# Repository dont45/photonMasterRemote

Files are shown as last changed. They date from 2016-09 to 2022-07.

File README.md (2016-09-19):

# photonMasterRemote
A photon Master Alarm system with any number of optional photon Remote nodes

See Wiki for lots more detail

Common source generates a master alarm node or a remote node.  
The master node is created by the #define PHOTON_MASTER line in parms.h.
A remote node is created by commenting out the master node #define , i.e. 
//#define PHOTON_MASTER which will result in a #define PHOTON_REMOTE
In addition, you must inclue the line #define REMOTE_SYSTEM_ID 1
The id number must be 1 or greater.  The id of the master node must be 0.

The master my have any number of it's own sensors defined in writeTestConfiguration.
The master's representation of a remote sensor is defined with device.use set to
SUB_REMOTE_THERMOMETER or SUB_REMOTE_SENSOR.  
The actual sensor is defined in the remote with master_idx set to the index number 
in the master which represents the remote sensor.

Communication of the remote sensor status is done via a particle.publish string which represents
the state of all of the remote sensors, such as:
3@1@T@13:12:16@TEST DOOR:2:0.000000:3@OUTSIDE TEMP:3:89.937500:0$
The @ character separates the first four data fields (sequence,remote id, alert type, and time).
Data for each sensor follows, also separated by an @ character.
These fields are parsed by the class Parse.

Each sensor's data fields are separated by a : character.  They are Name,device index in master,
and sensor reading.  These data fields are also parsed by class Parse.

The remote node publishes 'remoteData' to the particle cloud, and the master node is subscribed
to this cloud data field.  The remote node performs a publish immediately upon any sensor being
tripped, and also periodically as an Information update on a specified schedule, set in
parms.h.  This allows for immediate response to an alarm condition and periodic read on the
master node of other less time-sensitive data such as a temperature probe.  Upon receipt of the
subscribed remoteData, the master device is update with the new sensor data, stored into the
device record as dev_reading, and the current time is stored into dev_last_read.

In my operational test system, the hardware for both master and remote can be identical, except
for the attached sensors.  The remote node may also be of any custom design, as required.  It
only needs to publish a properly formatted data string as 'remoteData'.

I have implemented and tested the following configurations:

Master alarm in my house with sensors to read house temperature, boiler temperature, water detector,
fire alarm detector, motion detector, and magnetic door closure detectors.  All of these sensors
are 1-wire devices, such as a DS2413, DS1820, etc.  Temperature sensors can be either a 1-wire
device such as a DS18B20 or an I2C attached device such as an MCP9808 precision thermometer.
All 1-wire devices are attached to the photon by use of an I2C to 1-wire interface chip, the DS2482.
My home alarm / monitor system also includes two remote nodes.  Both of these nodes are implemented
with identical physical hardware, my custom PCB manufacture by PCBway from my Eagle design files.
The two remote nodes are 1) a remote alarm installed in my storage shed with a door sensor and an 
MCP9808 reading outside temperature, and 2) a remote node installed in my garage with a door sensor
for each garage door, motion-detector to cover the garage area, and a door sensor on the entry door
to the house.   This was implemented as a remote node in order to eliminate physical wiring back to
the master alarm.

I have also tested two unusual remote nodes.  One a battery powered photon with an ultrasonic distance
measurement device to read the hone heating fuel tank level.  See class Tank.
The second remote node is an Particle Electron based node installed in my truck which reads ambient 
temperature using an MCP9808 sensor, and transmits alarms if the temperature exceeds the device
settings.  It also sends a periodic Informational message of worry Temp.  This is to protect
my dog from dangerous heat while being left in the truch for short periods of time.  Both of these
remote nodes function like any remote node.  They simply publish 'remoteData' which is processed
by the master alarm.  Me and my truck can be thousands of miles away from home, and my home master
alarm functions to handle these high-temperature alerts from my truck to my iPhone just like any other
alarm sensor.

The master alarm publishes some data but the principal communication
to the user is done using web hooks to send alerts to my iPhone via Pushover.  

I have designed an iPhone app which communicates to the master alarm node.  The iPhone app receives a
minimal amount of data from the master directly.  These include alarm state and the current temperature
from one selected probe.  I have it configured to report the outside temperature from the shed.

A large amount of detail of the alarm configuration and current state is available by selection from
a drop-down menu in the app.  The resulting data is pushed to the iPhone as an alert message.
The commands available in the drop-down are:
HLP Help lists the available commands
ABT About tells a little about the system including the version
TMP Displays the current reading of all Temperature Sensors
SET Set the Alarm system to Enabled
DIS Disable the Alarm System
ACK Acknowledge an alarm condition
HOU Set the number of hours between worry pages
LIS List  basic information about sensors
NAM Set the Name of a sensor
SEN Show all detail of a sensor
ACT Set a sensor to active
DEA Disable a sensor
MIN Set minimum value to trigger an alert
MAX Set maximum value to tirgger an alert

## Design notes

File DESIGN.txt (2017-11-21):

//photonMasterRemote design

//November 16, 2017

Add Sensor type ALWAYS_DEVICE, now {HOME_DEVICE, ALWAYS_DEVICE, ALWAYS}
Purpose: smoke-detector, water detector, remotes run when 'house Master' is
disabled.

Add New Alarm State OFF, now {OFF, DISABLED, HOME, AWAY}
Purpose: OFF is old DISABLED, DISABLED is off except for ALWAYS sensors,
i.e. smoke-detectors etc.
u
//June 28, 2017

Garage Door Opener

Add to Sensor class or develop a new class??

Separate Door Sensors or Add new Sensors ??

Hardware Design:
Use ds2406 device:  Add new device type
PIO-B is door sensor
PIO-A is door button control
gpio port connects to one-show multivibrator to generate a 1/2 second pulse
pulse drives a 2n3904 which drives a relay, which is connected across button

Class properties:
canOpen : door control is allowed
canClose:

Class methods:
getDoorState() : read door state
openDoor() : open door, only if 1) Alarm is OFF, 2) door is closed, 3)door control is enabled
closeDoor() : close door, only if 1) door is open, 2) canClose is TRUE
pressDoorButton() : generate short pulse to PIO-A
doorDidClose() : follow up check of PIO-B that door closed, then send message
doorDidOpen() : follow up

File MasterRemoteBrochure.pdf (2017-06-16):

## A hardware platform designed as an alarm system core but capable of supporting many

different projects.

The circuit board is a simple design with a minimum of components created with EagleCad and manufactured by a custom board house. The IoT microprocessor is a Particle Photon. The board provides connections to the I2C interface and to two independent 1-wire networks. Many different sensor types can be connect to these interfaces.

Two LED’s provide
system and alarm status
and a button provides a
hardware reset.

The software system is a
comprehensive system
than can, by definitions
selected in a parameter
file, create a master or
remote systems. The
sensors, such as a
magnetic switch or a
motion detector are
connected to the 1-wire
bus through various 1-
wire GPIO devices. Many
other types of
environmental or other types may be connected to the provided interface busses. The software is written entirely in c++ and is designed using c++ objects implemented with c++ classes which model the concept being implemented.

The system is monitored and managed via an iPhone app written in Swift. Communication to the alarm user and to other parties is performed using the Pushover alert notification system. The system, both master and remotes, communicate only to the Particle Cloud via WiFi (Photon) or Cellular (Electron).

All communication between the alarm nodes themselves as well as communication with the iPhone control app is via the Particle cloud. Alarm conditions and many other informational and configuration messages are handle by web-hook calls from the cloud to Pushover. Intercommunication with the iPhone app is done via Particle functions and variables. See https://github.com/dont45/photonMasterRemote/.

1

## Internet of Things Alarm Platform

## Master Remote Alarm

2

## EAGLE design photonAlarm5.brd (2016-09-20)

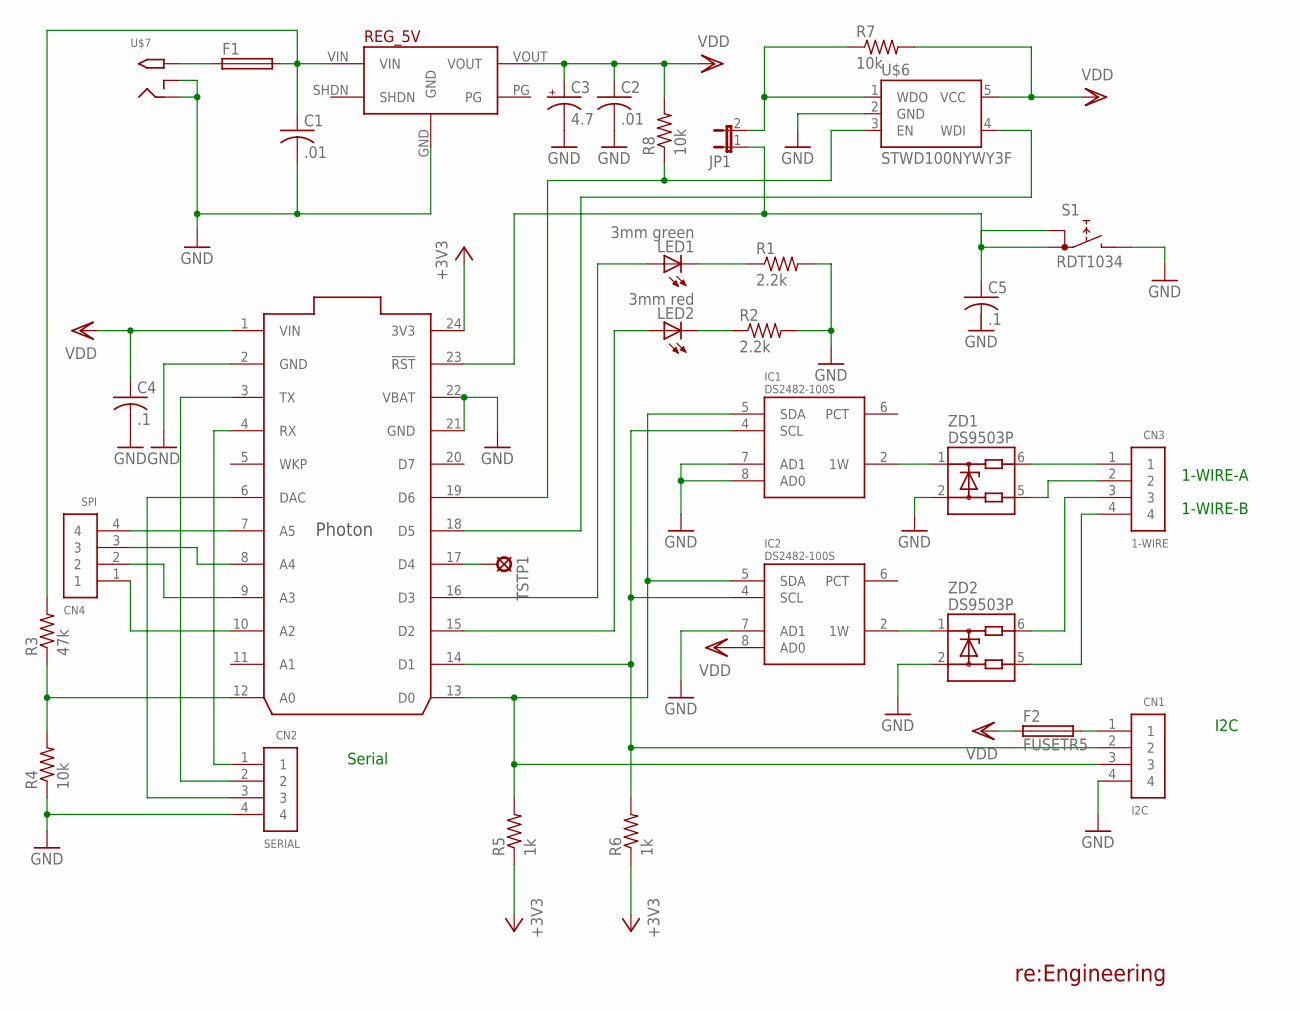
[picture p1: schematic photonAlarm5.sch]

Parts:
C1, C2: .01; C0805
C3: 4.7; E2,5-6E
C4, C5: .1; C0805
CN1: I2C; 1X04-BIG
CN2: SERIAL; 1X04-BIG
CN3: 1-WIRE; 1X04-BIG
CN4: SPI; 1X04-BIG
F1: PICOFUSE
F2: FUSETR5; TR5
IC1, IC2: DS2482-100S; SO08
JP1: JP1E; JP1
LED1: 3mm green; LED5MM
LED2: 3mm red; LED5MM
R1, R2: 2.2k; R1206
R3: 47k; R1206
R4, R7, R8: 10k; R1206
R5, R6: 1k; R1206
REG_5V: 5V_D24V10FAD24V10F5MIR; 5V_D24V10F5
S1: RDT1034
TSTP1: LSP10
U$1: PHOTON_WITH_HEADERS; PHOTON
U$6: STWD100NYWY3F; SOT23-5
U$7: 2.1MMJACKSMT; DCJACK_2MM_SMT
ZD1, ZD2: DS9503P; TSOC6

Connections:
+3V3: R5.1, R6.1, U$1.24 (3V3)
GND: C1.2, C2.2, C3.-, C4.2, C5.2, CN1.4, CN2.4, IC1.3 (GND), IC1.7 (AD1), IC1.8 (AD0), IC2.3 (GND), IC2.7 (AD1), R1.2, R2.2, R4.1, REG_5V.GND, S1.B, U$1.2 (GND), U$1.21 (GND), U$1.22 (VBAT), U$6.2 (GND), U$7.GND (RING), U$7.GNDBREAK (RING_SW), ZD1.2, ZD2.2
unnamed: TSTP1.MP, U$1.17 (D4)
unnamed: CN1.2, IC1.4 (SCL), IC2.4 (SCL), R6.2, U$1.14 (D1)
unnamed: LED1.K (C), R1.1
unnamed: LED2.K (C), R2.1
unnamed: LED1.A, U$1.16 (D3)
unnamed: LED2.A, U$1.15 (D2)
unnamed: CN1.3, IC1.5 (SDA), IC2.5 (SDA), R5.2, U$1.13 (D0)
unnamed: IC1.2 (1W), ZD1.1
unnamed: R3.1, R4.2, U$1.12 (A0)
unnamed: IC2.2 (1W), ZD2.1
unnamed: CN3.3, ZD2.6
unnamed: CN3.4, ZD2.5
unnamed: CN3.2, ZD1.5
unnamed: CN3.1, ZD1.6
unnamed: CN2.1, U$1.4 (RX)
unnamed: CN2.2, U$1.3 (TX)
unnamed: CN2.3, U$1.6 (DAC)
unnamed: U$1.18 (D5), U$6.4 (WDI)
unnamed: R8.1, U$1.19 (D6), U$6.3 (EN)
unnamed: CN1.1, F2.2
unnamed: CN4.4, U$1.7 (A5)
unnamed: CN4.3, U$1.8 (A4)
unnamed: F1.1, U$7.PWR2 (TIP)
unnamed: CN4.2, U$1.9 (A3)
unnamed: CN4.1, U$1.10 (A2)
unnamed: JP1.2, R7.1, U$6.1 (WDO)
RST: C5.1, JP1.1, S1.A, S1.A1, U$1.23 (!RST)
VDD: C2.1, C3.+, C4.1, F2.1, IC1.1 (VDD), IC2.1 (VDD), IC2.8 (AD0), R7.2, R8.2, REG_5V.VOUT, U$1.1 (VIN), U$6.5 (VCC)
VIN: C1.1, F1.2, R3.2, REG_5V.VIN

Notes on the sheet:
I2C
1-WIRE-A
re:Engineering
1-WIRE-B
Serial

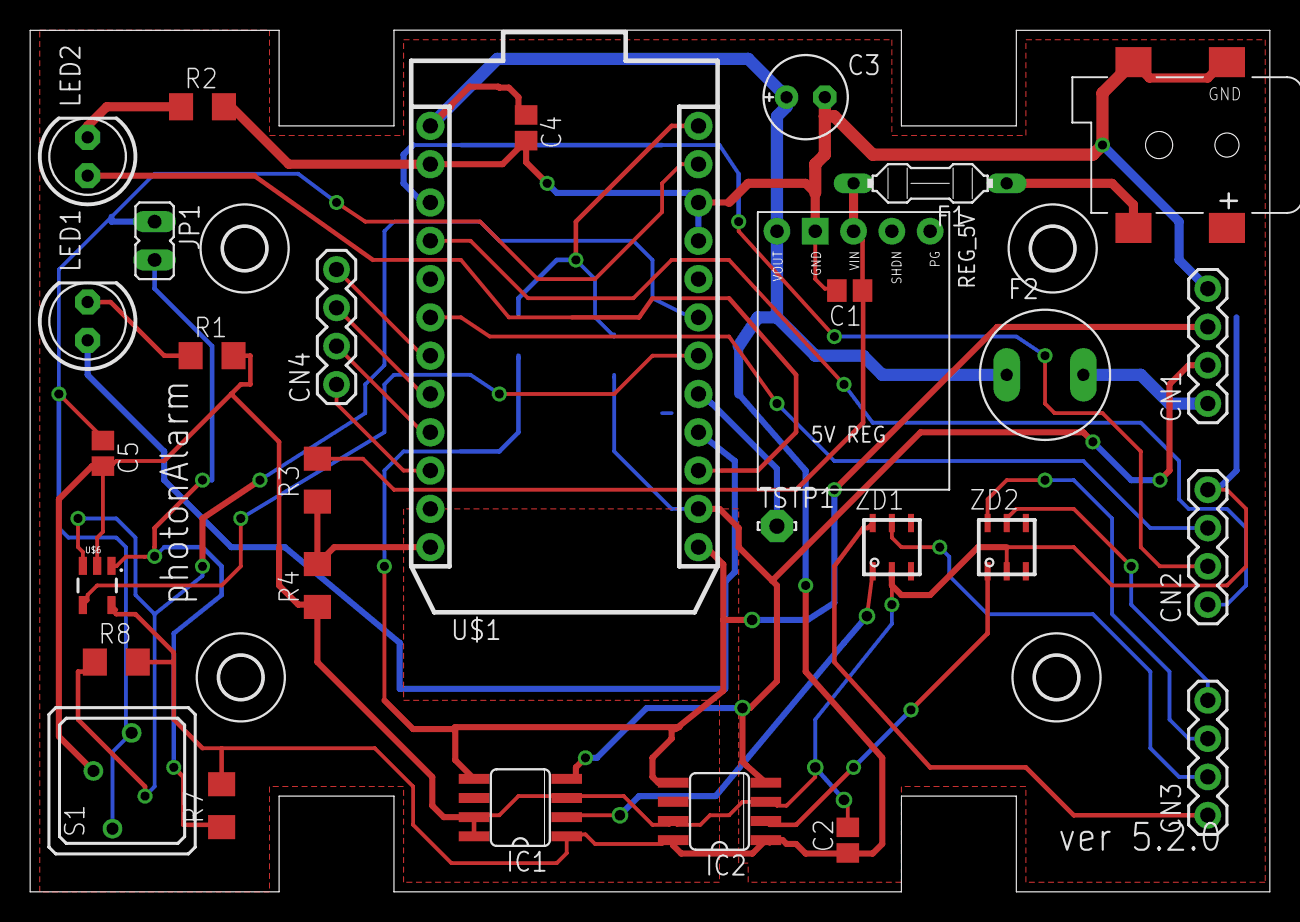
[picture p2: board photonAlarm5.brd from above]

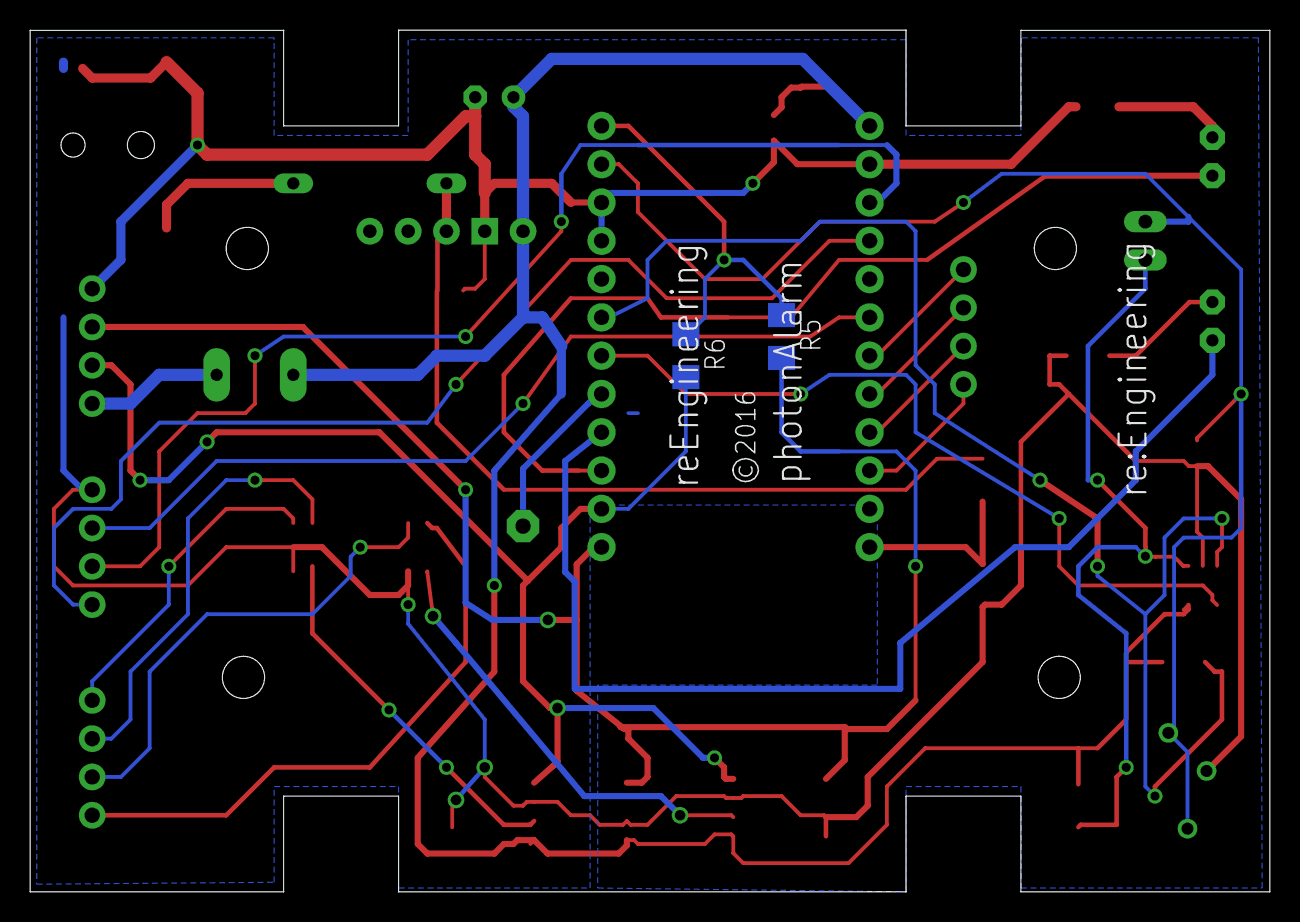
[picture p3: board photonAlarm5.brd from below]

Board: 2 copper layers, 82.2 x 57.1 mm, 36 parts (2 on the bottom side), 31 nets.

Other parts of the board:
U$2, U$3, U$4, U$5: 2,8

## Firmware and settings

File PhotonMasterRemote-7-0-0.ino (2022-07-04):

/*
  Master-Remote alarm system for Particle Photon
  @file     Alarm-Master.cpp
  @author   D. Thompson
  @license  GNU General Public License (see license.txt)
  @version  7.0

  Copyright (C) 2016 Donald Thompson, Raynham Engineering

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
  You should have received a copy of the GNU General Public License
  along with this program.  If not, see <http://www.gnu.org/licenses/>.
*/

/* Version 7.0.2
 * Redesign of remotes:
 * configure has one set of sensors
 * device.sys_id identifies which remote system sensor belongs to
 * readSensor only reads sensor if it belongs to itself
 */ 
/* Version 7.0.0
 * Redesign of devices:
 * Use common set of devices for master and remotes
 * upon config load set ??? based on master or remote
 * master_idx is no longer needed..idx is same for master and remote
 * Other changes to device_t ??
 * 
 * Add new published messages to keep remotes up to date ??
 */

/* Particle Cloud published events:
 * alarmState with name of new state any time state changes
 */
// To Do:
// a) fix sysState clearing to shut off blinking Status
//    USE a timer in sysState
//    Timer ext and in class cause build to fail
// b) fix multiple notifications upon alarm condition
// d) add i-button support as key and as config management
// e) add HTU21 humidity sensor support
// f) second 1-wire buss for i-button support (clear readint)
//    or can we skip-rom to just read class 01 == i-button ??
// g) add ds thermometer support

#include "application.h"
#include <queue>
#include <list>
#include "Adafruit_MCP9808.h"
#include "OW.h"
#include "parms.h"
#include "util.h"
#include "sensor.h"
#include "math.h"
#include "stdlib.h"
#include "parse.h"
#include "weather.h"
#ifdef HARDWARE_WATCHDOG
#include "hwd.h"
#endif
#ifdef MQTT_REMOTES
#include "MQTT.h"
#endif

//STARTUP(System.enableFeature(FEATURE_RETAINED_MEMORY));
//retained uint8_t testcurState;

int ledStatus = SYSTEM_STATUS_PIN;            //blink this LED at each loop pass
int ledNotice = SYSTEM_NOTIFICATION_PIN;      //blink this LED at each notification
int trigger3 = TRIGGER_PIN;
int message_countdown = 0;
//#ifdef PHOTON_MASTER
//double temperatureF;       remove                   // to publish
double temp_outside;                              // to publish
double temp_inside;                               // to publish
double temp_garage;                               // to publish
double temp_camper;                               // to publish
double gallonsO;                              // published oil gallons (demo)
double remote_temp;                           // published as temprmt
String stateA;
//#endif
#ifdef PHOTON_REMOTE
uint8_t remoteState;
uint8_t nextState;
char data[80];
String remoteData;
//String debugData = "testing";
int msgSeq = 0;
#endif

#ifdef MQTT_REMOTES
void callback(char* topic, byte* payload, unsigned int length);

/**
 * if want to use IP address,
 * byte server[] = { XXX,XXX,XXX,XXX };
 * MQTT client(server, 1883, callback);
 * want to use domain name,
 * exp) iot.eclipse.org is Eclipse Open MQTT Broker: https://iot.eclipse.org/getting-start
ed
 * MQTT client("mqtt.eclipse.org", 1883, callback);
 * MQTT client("test.mosquitto.org", 1883, callback);
 * my raspberry pi:
 byte server[] = { 192,168,0,50 };  //rpi
 MQTT client(server, 1883, callback);
 */
 MQTT client("test.mosquitto.org", 1883, callback);

// for QoS2 MQTTPUBREL message.
// this messageid maybe have store list or array structure.
uint16_t qos2messageid = 0;

// recieve message
void callback(char* topic, byte* payload, unsigned int length) {
    char p[length + 1];
    memcpy(p, payload, length);
    p[length] = NULL;
#ifdef SERIAL_DEBUG
    Serial.print("MQTT data:");
    Serial.println(p);
#endif
/*
    if (!strcmp(p, "RED"))
        RGB.color(255, 0, 0);
    else if (!strcmp(p, "GREEN"))
        RGB.color(0, 255, 0);
    else if (!strcmp(p, "BLUE"))
        RGB.color(0, 0, 255);
    else
        RGB.color(255, 255, 255);
    delay(1000);
*/
}

// QOS ack callback.
// if application use QOS1 or QOS2, MQTT server sendback ack message id.
void qoscallback(unsigned int messageid) {
    Serial.print("Ack Message Id:");
    Serial.println(messageid);
}
#endif

//#ifdef HARDWARE_REQUIRED_MSCP9808
Adafruit_MCP9808 mcp9808;
//#endif
OW ow(0);       //default 0 is 0x18 !!
// OW ow1(1);   //NO! testing second ds2483 for iButtons
// iButton ib(1);
// we SHOULD make a specific iButton class, similar to OW

#include "state.h"
State sys;

// remote data stream parser
//constructor with data
Parse::Parse(String d) {
  remotedata = d;
  idx = 0;
  parsePos = 0;
  elementDelimiter = ELEMENT_DELIMITER;
  endDelimiter = END_DELIMITER;
}
//constructor with data and delimiters
Parse::Parse(char elementd, char endd, String d) {
  remotedata = d;
  idx = 0;
  parsePos = 0;
  elementDelimiter = elementd;
  endDelimiter = endd;
}
//set data to parse
void Parse::setData(String s) {
  idx = 0;
  parsePos = 0;
  //remotedata.assign(s);
  remotedata = String(s);
  elementDelimiter = ELEMENT_DELIMITER;
  endDelimiter = END_DELIMITER;
}
void Parse::setDelimiters(char d_element, char d_end) {
  elementDelimiter = d_element;
  endDelimiter = d_end;
}
//set data to parse with special delimiters
void Parse::setData(char elementd, char endd, String s) {
  idx = 0;
  parsePos = 0;
  //remotedata.assign(s);
  remotedata = String(s);
  elementDelimiter = elementd;
  endDelimiter = endd;
}

// get the input string
String Parse::getData() {
  return remotedata;
}

int Parse::parseNext(int pos, int end) {
  //char lastc;
  if(pos) pos++;
  element[idx] = remotedata.substring(pos, end);
  idx++;
  return idx;
}

//find position of next delimiter in remotedata
int Parse::findDelim(char delimiter, int start) {
  parsePos = remotedata.indexOf(delimiter, start+1);
  return parsePos;
}

String Parse::getElement(int idx) {
  return element[idx];
}

//do parse into parsed_elementU
int Parse::doParse() {
  int start = 0;
  int end = 0;
  int n;
  for(n=0;n<MAX_PARSED_ITEMS;n++) {
    end = findDelim(elementDelimiter, start);
    if(end < 0) end = findDelim(endDelimiter, start);
    if(end < 0) break;
    parseNext(start,end);
    start = end;
  }
  el4=element[4]; //kluge, [] gives error ?????
  return n;  // parsed n elements
}

#include "notifier.h"

// ADDED new member function to set status ?????
void Sensor::setDeviceStatus(device_t d, bool toPresent) {
    if(toPresent)
      d.status = DEV_PRESENT;  //XXXXXXXXX
    else
      d.state = DEV_MISSING;
}
  
void Sensor::setDeviceActive(device_t *d, bool toActive) {
    if(toActive)
      d->state = SENSOR_ACTIVE;
    else {
      d->state = SENSOR_DISABLED;
      if(d->dev_use >= FIRST_SUB_REMOTE) { //a REMOTE device
        d->dev_reading = 0;
        d->dev_last_read = 0;
        d->tripped = FALSE;
        d->reported = FALSE;
      }
    }
}
//------------------
void Sensor::setDeviceSense(device_t *d, uint8_t newSense) {
  if(newSense <= 1)
    d->sense= newSense;
}

void Sensor::setDeviceLevel(device_t *d, uint8_t newLevel) {
  if(newLevel <= 2)
    d->alert_level = newLevel;
    //else message
}
//------------------
// set sensor indicator (on PIO_A)
void Sensor::setSensorIndicator(device_t d, uint8_t indval) {
  #ifdef SERIAL_DEBUG_SEN
  Serial.print("setting indicator:");
  Serial.println(indval);
  #endif
  //#define PIO_A 0
  //#define PIO_B 1
  //d.port is the sensor read port
  //indicator port is the other one ??
  uint8_t indicator_port = d.port ? 0 : 1;
  //debug
  uint8_t op_value = indval ? 0 : 1;
  #ifdef SERIAL_DEBUG_SEN
    Serial.print("setSensorIndicator:port=");
    Serial.print(d.port);
    Serial.print(" indicator port=");
    Serial.print(indicator_port);
    Serial.print(" led=");
    Serial.println(indval);
  #endif
  //debug: (2 lines)
  //p_ow->writePIOtest(d.dev_rom, indicator_port, op_value);  //WRITE TO PIO-x
  //delay(500);
  p_ow->writePIOtest(d.dev_rom, indicator_port, indval);  //WRITE TO PIO-x
}

// return TRUE if tripped
// TO DO: FIX reading of MCP9808 master vs remote sensor
// master reads device, remote just returns dev_reading
// BUG: ??  dev_last_read not updating for SUB_REMOTE ???
// Prints SUB_REMOTE_SENSOR: ... on every loop ?????
bool Sensor::readSensor(device_t &d) {
    uint8_t senval;
    uint8_t prev_senval;
    //uint8_t sensor_priority = 0;  //reporting priority
    double tempF;
    //double oilL;
    bool senret;
    bool rok;
    bool toSetSensor;
    float reading;
// --------
   if((REMOTE_SYSTEM_ID) && (d.sys_id != REMOTE_SYSTEM_ID)) {
    #ifdef SERIAL_DEBUG_SENXXX
      Serial.print("Device Not Ours:");
      Serial.print(d.idx);
      Serial.print("  :");
      Serial.println(d.name);
    #endif
      return FALSE;
    }
 //--------
    if(d.status != DEV_PRESENT) {
  #ifdef SERIAL_DEBUG_SEN
      Serial.print("Device Missing:");
      Serial.print(d.idx);
      Serial.print("  :");
      Serial.println(d.name);
  #endif
      return FALSE;
    }
    if(d.state == SENSOR_DISABLED) {
  #ifdef SERIAL_DEBUG_SEN
      Serial.print("Device deactivated - ROM:");
      Serial.println(d.dev_rom[7],HEX);
  #endif
      return FALSE;
    }
    d.changed = FALSE;
    #ifdef SERIAL_DEBUG_SEN_READ
            Serial.print("readSensor name=");
            Serial.print(d.name);
            Serial.print(" port=");
            Serial.print(d.port);
            Serial.print(" use=");
            Serial.print(d.dev_use);
            Serial.print(" master=");
            Serial.println(d.master_idx);
    #endif

    switch(d.dev_use) {
      case SWITCH:    //USE IO_SENSOR
  #ifdef SERIAL_DEBUG_SEN_READ
          Serial.print("readSensor name=");
          Serial.print(d.name);
          Serial.print(" port=");
          Serial.print(d.port);
          Serial.print(" use=");
          Serial.print(d.dev_use);
  #endif
         senval = digitalRead(d.port);
         reading = (float)senval;
         //move this out of switch
         if(abs(d.dev_reading - reading) < 0.1) d.changed = TRUE;
         d.dev_reading = reading;
         d.dev_last_read = Time.now();
  #ifdef SERIAL_DEBUG_SEN_READ
          Serial.print(" readvalue=");
          Serial.println(senval);
  #endif
          return senval==d.sense;
          break;
      case IO_SENSOR:  //SAME AS SWITCH ??
          // read hardware port d.dev_addr
          prev_senval = d.dev_reading;
          senval = digitalRead(d.port);
          reading = (float)senval;
#ifdef SERIAL_DEBUG_SEN_READ
            Serial.print("readSensor name=");
            Serial.print(d.name);
            Serial.print(" port=");
            Serial.print(d.port);
            Serial.print(" use=");
            Serial.print(d.dev_use);
            Serial.print(" sensel=");
            Serial.print(d.sense);
            Serial.print(" senval=");
            Serial.print(senval);
            Serial.print(" prev_senval=");
            Serial.println(prev_senval);
 #endif
          d.changed = senval != prev_senval;
          d.dev_reading = reading;
          d.dev_last_read = Time.now();
          senret = senval==d.sense;
#ifdef SERIAL_DEBUG_SEN_READ
          if(d.changed) {
            Serial.print("readSensor name=");
            Serial.print(d.name);
            Serial.print(" port=");
            Serial.print(d.port);
            Serial.print(" use=");
            Serial.print(d.dev_use);
            Serial.print(" sensel=");
            Serial.print(d.sense);
            Serial.print(" senval=");
            Serial.print(senval);
            Serial.print(" prev_senval=");
            Serial.print(prev_senval);
            Serial.print(" senret=");
            Serial.print(senret);
            Serial.print(" changed=");
            Serial.println(d.changed);
          }
#endif
          return senret;
          break;
      case OW_SENSOR:
      case OW_INDICATOR:  //one-wire device on DS2482-100
          senval = p_ow->readPIOX(d.dev_rom, d.port);    //??just readPIO and use d.port
          toSetSensor = (uint8_t)d.dev_reading != senval;
          prev_senval = d.dev_reading;
          reading = (float)senval;
          d.changed = senval != prev_senval;
          d.dev_reading = reading;
          //............
          d.dev_last_read = Time.now();
          senret = senval==d.sense;
          #ifdef SERIAL_DEBUG_SEN
                    if(d.changed) {
                      Serial.print("readSensor OW_SENSOR name=");
                      Serial.print(d.name);
                      Serial.print(" port=");
                      Serial.print(d.port);
                      Serial.print(" use=");
                      Serial.print(d.dev_use);
                      Serial.print(" sense=");
                      Serial.print(d.sense);
                      Serial.print(" senval=");
                      Serial.print(senval);
                      Serial.print(" prev_senval=");
                      Serial.print(prev_senval);
                      Serial.print(" senret=");
                      Serial.println(senret);
                    }
          #endif
          if(d.dev_use==OW_INDICATOR)
            //if(toSetSensor) setSensorIndicator(d, senret);
      #ifdef SERIAL_DEBUG_SEN
            Serial.print("setSensorIndicator:");
            Serial.println(d.idx);
      #endif
            setSensorIndicator(d, senret);
          return senret;
          break;
      // TODO: Implement??
      // This should set 'this' remote active, not just this one device
      // Bug: it is NOT this device to set active
      // how do we tell it what device ??
      // use master_idx ??
      case SUB_SET_DEVICE: // DESIGN: set remote active
        if(d.dev_last_read > Time.now() - DEVICE_TIMEOUT) {
        //if(Time.now - d.dev_last_read > DEVICE_TIIMEOUT) {
              if(d.dev_reading > 0.5){
                //DO WE REALLY WANT TO DO THIS??
                //remote status is controlled by user / cmd RON / ROF ??
                sys.setRemoteStatus(d.idx,TRUE);
                 // and send message it's set ???
                 //BUG:need alarm1 in scope ?????
                //alarm1.tellRemote(d.master_idx,'R');
              }
              d.dev_reading = 0.0;
            }
          break;
      case SUB_REMOTE_SENSOR:
          // validat dev_last_read: DEVICE_TIMEOUT = 1/2 HR TOO long??
          if(!sys.getRemoteStatus(d.master_idx)) return FALSE; //REMOTE not enabled (id??)
          if(d.dev_last_read > Time.now() - DEVICE_TIMEOUT) {
            senval = d.dev_reading;
            senret = senval==d.sense;
            #ifdef SERIAL_DEBUG_REMOTEXX
                Serial.print("SUB_REMOTE_SENSOR: remotesys=");
                Serial.print(d.master_idx);
                Serial.print(" senretl=");
                Serial.println(senret);
            #endif
              return senret;
          }
          else {
#ifdef SERIAL_DEBUG_SEN
              Serial.println("SUB_REMOTE:time expired ");
#endif
              return FALSE;
          }
          break;
      case SUB_REMOTE_THERMOMETER:
          if(!sys.getRemoteStatus(d.master_idx)) return FALSE; //REMOTE not enabled (id??)
          if(d.dev_last_read > Time.now() - DEVICE_TIMEOUT) {
            senval = d.dev_reading;
            if(d.alert_max && (senval > d.alert_max)) return TRUE;
            if(d.alert_min && (senval < d.alert_min)) return TRUE;
            return FALSE;
          }
          else {
#ifdef SERIAL_DEBUG_SEN
              Serial.println("SUB_REMOTE_TH:time expired ");
#endif
              return FALSE;
          }
            break;
      case SUB_OIL_GAUGE:        //demo particle.subscribe value
              //last_oil_level is updated by subscription
              //d.dev_reading = last_oil_level;
              if(d.dev_reading < -1000.0) return FALSE;
              if(d.dev_last_read < Time.now() - DEVICE_TIMEOUT) {
                d.dev_reading = -1001.0;
                d.state=SENSOR_INACTIVE;
                return FALSE;
              }
              if(d.alert_min !=0 && d.dev_reading <= d.alert_min)
                return TRUE;
              //sensor can trip based upon notification levels
              //green condition = no notification or -1??
              //yellow condition = 0
              //red condition = priority = 1
              return FALSE;
          break;
      case SUB_CAR_MONITOR:    //sub-sensor via particle.subscribe value
              //dev_reading is updated by subscription (remoteHandler)
              // 1) temp received compared to max setting
              if(d.dev_reading < -1000.0) return FALSE;
              if(d.dev_last_read < Time.now() - DEVICE_TIMEOUT) {
                d.dev_reading = -1001.0;
                d.state=SENSOR_INACTIVE;
                //notifier.queueMessage(SHORT_HEADER,1,"Car Monitor Inactive");
                return FALSE;
              }
              if(d.alert_max !=0 && d.dev_reading >= d.alert_max)
                return TRUE;
              // 2) time-stamp of last data received
              // 3) return TRUE if alert condition
              return FALSE;     // TO DO: alert if temp < ??
          break;
//#ifdef HARDWARE_REQUIRED_MSCP9808
      case MCP9808_THERMOMETER:  //precision thermometer on I2C
              // readTempF should use config parameters to get device info
              // i.e. i2c address etc.  This allows multiple devices on bus
              last_temp = mcp9808.readTempF();
  #ifdef SERIAL_DEBUG_SEN_READ
              Serial.print("READ MCP...");
              Serial.print(last_temp);
              Serial.print(" dev:");
              Serial.println(d.dev_reading);
  #endif
              reading=d.dev_reading;
              d.dev_reading = last_temp;
              d.dev_last_read = Time.now();
              // return value should  be tripped if outside temp range ??
              // report using priority of sensor ??
//#endif
#ifdef PHOTON_REMOTE
              //REPORT to mastert if temp changed
              if(abs(last_temp - reading)>0.1) {
                  //Serial.println("temp diff!");
                  return TRUE;
               }
#else
              if((int)last_temp <= d.alert_min) return TRUE;
              // readTemp should return an error condition ??
#endif
              return FALSE;
        break;
        case OW_THERMOMETER:    //ds1820 thermometer
            #ifdef SERIAL_DEBUG_THERM
              Serial.print("ds1820 testing-rom:");
              for(int i=0;i<8;i++) {
                Serial.print(d.dev_rom[i],HEX);
                Serial.print("-");
              }
              Serial.println();
            #endif
              d.dev_reading = -999.0; //if read fails
              rok = p_ow->readThermometer(d.dev_rom, tempF);
              if(rok) {
                d.dev_reading = tempF;
                d.dev_last_read = Time.now();
            #ifdef SERIAL_DEBUG_THERM
                Serial.print("temp Fahrenheit x100:");
                Serial.println((int)tempF*100);
            #endif
                if((int)tempF <= d.alert_min) return TRUE;
              }
              return FALSE;  //not tripped
        break;
      default:
        break;
  }
  return FALSE;
}

//clear changedSenbsors
void Sensor::clearChangedSensors() {
  changedList.clear();
  trippedSensor = FALSE;
}

//add sensor to changedList
void Sensor::addChangedSensor(device_t sp) {
    changedList.push_back(sp);
    trippedSensor = TRUE;
}
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
void loop() {
  //debug: ??? REMOVE THIS
  /*
  if(dlc++){
    dlc = 0;
    digitalWrite(MESSAGE_PIN, HIGH);
  } else {
    digitalWrite(MESSAGE_PIN, LOW);
  }
  */
  // END DEBUG
  char msgType; //in {Tripped,Clear,Notify,Reset,Info}
  bool do_master_send = notify.checkTime();
  //DEBUG:
  //Debug: force all sensor check every loop
  //do_master_send = TRUE;  //Debug: <<<===
  if(do_master_send) msgType = 'I';
  //Serial.println(do_master_send);
  //DESIGN??
  //We need to FORCE ALL SENSORS inot ChangedSensor if checkTime ??
  bool t = alarm1.checkSensors(do_master_send);
  String changed = sensor.fmtChangedSensors();  //<<<=== report all if 'I' ??
  #ifdef SERIAL_DEBUG_SEN
  Serial.print("checkSensors returned:");
  Serial.println(t);
  Serial.print("changedSensors:");
  Serial.print(changed);
  if(sensor.hasChangedSensor()) Serial.println(" hadChanged");
  Serial.print("remoteState=");
  Serial.print(alarm_state_name_def[remoteState]);
  #endif
  if(sensor.hasChangedSensor()) do_master_send = TRUE; //OR from checkTime
  if(do_master_send) {
    //data format:
    //  messageid@system_id@A@hh:mm:ss@sensor-name:masterIdx:reading:?^...second sensor...$
    char sensordata[100]; //SIZE??
    //if(sensor.hasTrippedSensor())  //why doesn't work?
    if(alarm1.isTripped()) msgType = 'T';
    //else
    //  msgType = 'C';  //DESIGN ?? need to use State??
    //  why don't we send all sensors ??? BUG??
    String time = Time.format("%H:%M:%S%S");
    sprintf(data,"%d@%d@%c@%s%s$",msgSeq++,sys.getSysId(),msgType,time.c_str(),changed.c_str());
    String rData = String(data);
    remoteData = rData;
    #ifdef SERIAL_DEBUG
    Serial.println(data);
    #endif
    Particle.publish("remotedata", rData);
#ifdef MQTT_REMOTES
    client.publish("photon/remote",rdata, MQTT::QOS2);
#endif
#ifdef SERIAL_DEBUG_CLOUD
    Serial.print("remotedata=");
    Serial.print(rData);
#endif
    alarm1.clearSensorReported();
    //digitalWrite(MESSAGE_PIN, HIGH);       //blink red led on publish
  }
  delay(REMOTE_LOOP_DELAY_TIME); //use two delays to show led
  alarm1.doStatusBlink();
  #ifdef SERIAL_LOOP_WAIT
    while(!Serial.available())  // Wait here until the user presses ENTER
      Spark.process();          // in the Serial Terminal. Call the BG Tasks
    Serial.read();
//  #else
  #endif
  //digitalWrite(MESSAGE_PIN, LOW);       //blink red led on publish
  nextState = remoteState;
}
#endif  //PHOTON_REMOTE

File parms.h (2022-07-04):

/*
  @file     parms.h
  @author   Don Thompson (raynham Engineering)
  @license  GNU (see license.txt)

  Configuration parameters
  Copyright (C) 2016 Don Thompson, Raynham Engineering

  Raynham MA
 */

#ifndef __PARMS_H__
#define __PARMS_H__

#define SYSTEM_VERSION_MAJOR 7
#define SYSTEM_VERSION_MINOR 0
#define SYSTEM_VERSION_SUB 3

// BOSTON
#define EDT_OFFSET -4
#define EST_OFFSET -5
// LAS VEGAS
#define PST_OFFSET -8
#define PDT_OFFSET -7
#define TIME_OFFSET PDT_OFFSET
#define SYSTEM_CONFIGURATION
//  COMPILES WITH BOTH
// <<<>>>Define which to compile here
#define PHOTON_MASTER   // <<<=== Build MASTER or Remotes
// <<<>>> Define MASTER OR REMOTE on Line Above
#ifndef PHOTON_MASTER
#define PHOTON_REMOTE
#define PHOTON_REMOTE_1   // GARAGE REMOTE on Argon:
//#define PHOTON_REMOTE_2 // AIRSTREAM on BORON
#endif

//all debugs defined here
#ifdef PHOTON_REMOTE
#define SERIAL_DEBUG
//#define SERIAL_DEBUG_REMOTE
//#define SERIAL_DEBUG_OW
//#define SERIAL_DEBUG_WIRE
//#define DEBUG_AQUIRE
//#define SERIAL_DEBUG_SEN
//#define SERIAL_DEBUG_THERM
//#define SERIAL_DEBUG_ALARM
//#define SERIAL_DEBUG_CLOUD
//#define HARDWARE_WATCHDOG
//#define DEBUG_PARSE_ELEMENT
//#define DEBUG_PARSE_DETAIL
//this disables all but ONE sensor <<<===
//#define DEBUG_ONLY_ONE_SENSOR
//#define DEBUG_THIS_SENSOR 3
//#define SERIAL_DEBUGXX
//#define SERIAL_DEBUG_EVENT
//#define SERIAL_DEBUG_CONFIG
//#define SERIAL_WAIT
//#define SERIAL_LOOP_WAIT
#define HALT_ON_HDW_ERROR          //DISABLE FOR TESTING
#endif

//Testing Master-Remote WITH NEShed as master
#ifdef PHOTON_MASTER
#define REMOTE_SYSTEM_ID 0        // NOT a remote
#define SERIAL_DEBUG
//#define SERIAL_DEBUG_REMOTE
//#define SERIAL_DEBUG_WIRE
//#define SERIAL_DEBUG_OW
//#define SERIAL_DEBUG_I2C
//#define DEBUG_PARSE_ELEMENT
//#define COMMAND_DEBUG               // zero confirm on ALL
//#define MQTT_REMOTES                // using MQTT messaging
#define CHECKIN_DISABLED
#define EE_MAGIC_STATE 0x01
#define PUSHOVER_SEND_MESSAGES      //actually send Pushover Messages
#define WORRY_MINUTES 5             //time between follow-up notifications
//#define VERDI_FALLS_CONFIGURATION
#define REMOTE_NAMES "master","garage","camper","truck","greatrm","kitchen","",""
#define HARDWARE_REQUIRED_MCP9808
#define HARDWARE_REQUIRED_DS2482
//#define HALT_ON_HDW_ERROR          // skip halt for debug, 06/11/2021
#define MCP9808_I2CADDR  0X19       //cranky_jester
//#define MCP9808_I2CADDR  0X1A       //scrper_neshed  <<<MASTER UNIT
#endif

#ifdef PHOTON_REMOTE_1              //GARAGE on Argon BB
#define REMOTE_SYSTEM_ID 1
//#define GARAGE_CONFIGURATION
#define EE_MAGIC_STATE 0x05
#define WORRY_MINUTES 5             //time between follow-up notifications
#define HARDWARE_REQUIRED_MCP9808
#define HALT_ON_HDW_ERROR          // skip halt for debug, 06/11/2021
#define MCP9808_I2CADDR 0x18       //scrper_neshed 0x1A  A1, A0,A2 LOW
#define REMOTE_SENSOR_CHECK_MINUTES 10 //USE 15
//#define SERIAL_DEBUG_SEN_READ
//#define SERIAL_DEBUG_CONFIG
//#define DEBUG_ONLY_ONE_SENSOR
//#define DEBUG_THIS_SENSOR 0
#endif

#ifdef PHOTON_REMOTE_2              //AIRSTREAM on New Boron
#define REMOTE_SYSTEM_ID 2
#define HARDWARE_REQUIRED_MCP9808
#define MCP9808_I2CADDR 0x19        //cranky 0x19  A0 HIGH, A1,A2 LOW
//#define HARDWARE_REQUIRED_DS2482    // using one-wire
#define HALT_ON_HDW_ERROR           // skip halt for debug, 06/11/2021
#define EE_MAGIC_STATE 0x05
#define WORRY_MINUTES 15     // used in REMOTE?? time between follow-up notifications
#define REMOTE_SENSOR_CHECK_MINUTES 2 // debug: set to 10
#endif

//bench-board test configuration
//CONVERT TO IN-WALL living room controller
#ifdef SYSTEM_CONFIGURATION
#define MAXDEVICE 8
#define EE_MAGIC_CONFIG 0x06       // change this to write new test config
#define DEV_SENSOR_1               // GARAGE OVERHEAD
#define DEV_SENSOR_2               // GARAGE TEMP
#define DEV_SENSOR_10              // RED DS2013 OUTSIDE PATIO
#define DEV_SENSOR_11              // BLUE DS2013 INSIDE LR
#define DEV_SENSOR_12              // ORANGE: LR MOTION
#define DEV_SENSOR_13              // BLACK: LR SLIDER
#define DEV_SENSOR_14              // AIRSTREAM DOOR
#define DEV_SENSOR_15              // AIRSTREAM TEMP
#endif
#define INSIDE_THERMOMETER_IDX 3    //MAIN INSIDE TEMP
#define OUTSIDE_THERMOMETER_IDX 2   //MAIN OUTSIDE TEMP
#define GARAGE_THERMOMETER_IDX 1    //GARAGE TEMP
#define CAMPER_THERMOMETER_IDX 7    //CAMPER TEMP
#define SENSOR_LIST_SCAN
#define ALERT_HOURS 1               //??TESTING, S/B longer (3 or 6)
#define CHECKIN_HOURS 0b000000000000000000000000;  //10am 2pm 8pm
#define CHECKIN_EMERGENCY_MESSAGE  "DON FAILED TO CHECK IN "
#define LOOP_DELAY_TIME 250         //250: Debug: Delay ms between loop passes
#define REMOTE_LOOP_DELAY_TIME 250  //250: Debug: Delay ms between Loop on Remotes
//ledStatusBlink is style of blink: none,slow,fast
#define FAST_LED_BLINK_CNT 0
#define SLOW_LED_BLINK_CNT 3
#define MAX_ALARM_NOTIFIED 1000     //Global limit on published alarms (DEBUG limit                        )
#define SYSTEM_STATUS_PIN D2        //RED if Armed, Blinking if any tripped
#define SYSTEM_NOTIFICATION_PIN D3  //GREEN blinks at each loop ??
#define TRIGGER_PIN D6              //debug pin for logic analyzer trigger
//TODO: REVIEW USE OF THE NEXT THREE PINS ??
#define LOOP_SENSOR_PIN D6          //magnetic door loops
#define MOTION_LOOP_SENSOR_PIN D6   //motion detector
#define TAMPER_PIN D6               //system tamper switch loop
#define MESSAGE_PIN D7              //on-board led to show message limts reachec
#define RANDOM_MIN 1000             //range of random number for secret
#define RANDOM_MAX 9999
#define BAD_SECRET_MAX 3            //maximum bad secret tries in a row
// FOR PRODUCTION, MESSAGE_LOOP_DELAY S/B 1
#define MESSAGE_LOOP_DELAY 0        //number of loop passes btw notifications = 5secU
#define MAX_MESSAGE_PER_HOUR 100    //absolute maximum of pushover messages per hour
#define CLEARING_COUNT_MAX 60       //no. loops passes in notifying state
#define DEVICE_TIMEOUT 1800         // HALF HOUR
#define MAX_ALLOW_OWDEV  20         //absolute maximum of ow devices
#define FMLY_IBUTTON 0x01           //NOT USED ???
#define FMLY_2405 0x05
#define FMLY_2406 0x12              //and FMLY_2407
#define FMLY_1820 0x10
#define USE_FMLY_IBUTTON
#define USE_FMLY_2405
#define USE_FMLY_2406
#define USE_FMLY_1820
#define PIO_A 0
#define PIO_B 1
#define SENSOR_NAME_SIZE 16
#define ONE_DAY_MILLIS (24 * 60 * 60 * 1000)
//#define WD_EN 5                   // WatchDog enable PIN
//#define WD_WDI 6                  // WatchDog Timer Reset Input
#endif

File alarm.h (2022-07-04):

/*
  @file     alarm.h
  @author   Don Thompson (raynham Engineering)
  @license  GNU (see license.txt)

  Alarm class manages core alarm functions
  Copyright (C) 2016 Don Thompson, Raynham Engineering

  Raynham MA

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
  You should have received a copy of the GNU General Public License
  along with this program.  If not, see <http://www.gnu.org/licenses/>.
*/

#ifndef __ALARM_H__
#define __ALARM_H__
#include "application.h"
#include "parms.h"
#include <queue>
#include <list>
#include <map>

// Alarm states xxx  FIX:???
// need two states: alarm_state; DISARMED, armed
// and sensor_state: clear, tripped, notified
enum {alarm_off=0,alarm_disarmed=1,alarm_armed=2,alarm_tripped=3,alarm_notifying=4,alarm_clearing=5,alarm_reported=6,remotes_enabled=7,remotes_disabled=8,remotes_query=9};
const char* alarm_state_name_def[10] = {"SYSTEM OFF", "DISARMED", "ARMED", "TRIPPED", "NOTIFY", "CLEAR", "REPORTED","REM-ENA","REM_DIS","REM_QRY"};
const char alarm_state_short[10] = {'F','D','A','T','N','C','R','X','O','Q'};
enum {AT_HOME=0, AWAY=1};
const char* alarm_state_location_def[2] = {"HOME", "AWAY"};
enum {LED_OFF, LED_SOLID, LED_SLOW, LED_FAST};

class Alarm {
public:
  Alarm() {
    prevTripState = FALSE;
    firstTrippedSensor=0;  //?? use tripedList
    clearing_cnt = 0;
    p_config = new config_t;
    priority = 0;
    ledStatusState = 0;
    ledStatusBlink = 0;                       // 0=solid,1=slow blink,2=fast blink
    ledStatusBlinkCount = 0;
  }
  ~Alarm();
  //old: set state explicitly, with rules ??
  bool setState(uint8_t new_state);
  //new: set state -- state machine
  int setState();
  uint8_t getState();
  uint8_t getLocation();
  uint8_t getbaseState();
  String getStateDescription();
  String getStateDescription(uint8_t);
  bool readSavedState();
  bool writeSavedState();
  bool generateConfiguration();
  bool readConfiguration();
  bool writeTestConfiguration();
  bool updateConfiguration(device_t* dev, int n);
  uint8_t buildDeviceList();
  void setValidNonWire();
  void dump_device_list();
  bool validate_device_list();
  char* deviceListing(char *buf);
  char* thermometerListing(char *buf);
  char* eventListing(char *buf);
  uint8_t wiredeviceAquire();
  bool wiredeviceValidate(uint8_t *ROM);
  bool isTripped();
  bool isReported();
  bool prevTripped();
  device_t *firstTripped();
  String tripListString();
  uint8_t formatRemoteTrip(char*);
  bool isArmed();
  void doStatusBlink();
  void clearing_countup();
  void blinkTimeout();
  bool alarmNotifying();
  String getPendingMessage();
  uint8_t getPriority();
  bool checkSensors(bool);
  String getLastTemperature();  //testing
  bool clearSensorReported();
  bool allClear();
  int clearingCount();
  device_t* getDevice(uint8_t); //v0.1.6
  device_t* getDeviceByUse(uint8_t); //v0.1.6
  bool setLastRemote(uint8_t, float);
  bool setAlarmRemote(uint8_t, uint8_t, uint8_t, float);
  //void setDeviceActive(device_t *d, bool);
  void setDeviceAlertMin(device_t *d, int p3);
  void setDeviceAlertMax(device_t *d, int p3);
  float readTemperature(uint8_t); //read by device idx
  void setCurLocation(uint8_t);
  uint8_t getCurLocation();
  bool devIsTripped(int);
  void resetDevice(uint8_t);
  int addEvent(uint8_t);
  int ackEvent(int);
  int removeEvent(int);
  bool eventsClear();
  void setRemotes(uint8_t);
  void tellRemote(uint8_t, char);
#ifdef PHOTON_REMOTE
  void setLEDRemote(char);
#endif
private:
  void setStatusLED();
  config_t configuration;
  config_t *p_config;
  uint8_t curState;
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

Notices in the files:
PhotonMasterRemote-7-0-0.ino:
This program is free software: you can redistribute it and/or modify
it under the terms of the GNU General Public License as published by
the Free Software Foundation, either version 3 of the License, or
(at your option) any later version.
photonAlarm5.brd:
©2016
